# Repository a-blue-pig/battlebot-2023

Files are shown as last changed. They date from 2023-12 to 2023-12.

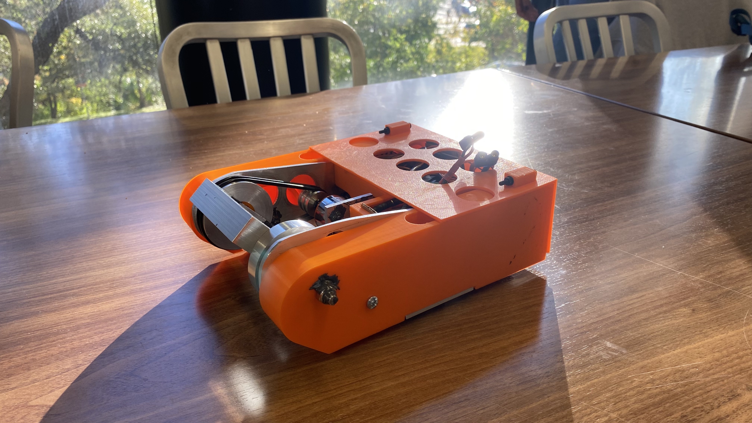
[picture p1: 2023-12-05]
pictures/IMG_2329.jpeg

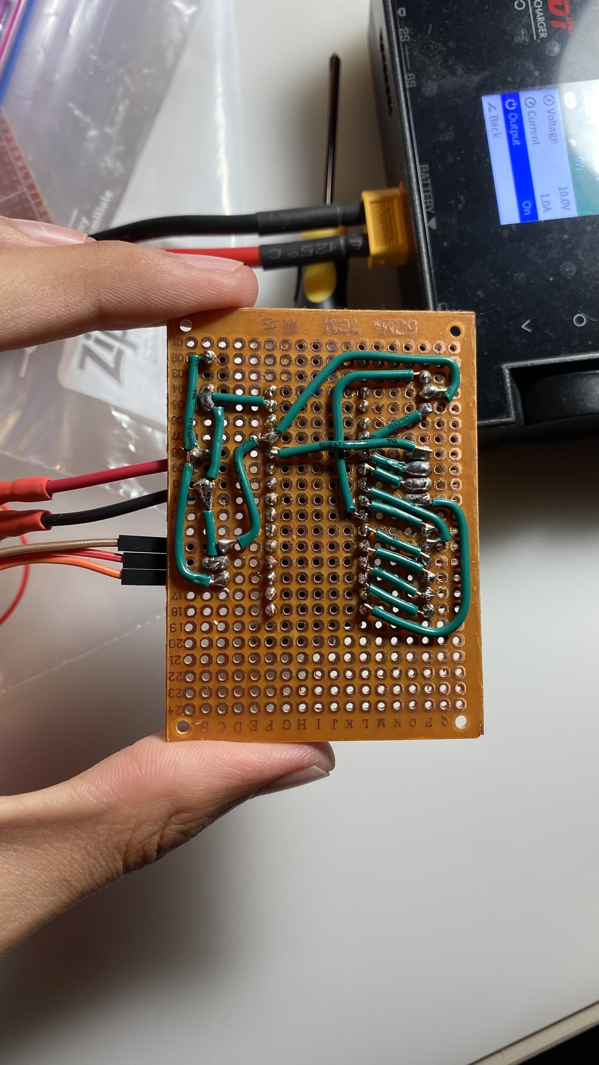
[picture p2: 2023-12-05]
pictures/IMG_2281.jpeg

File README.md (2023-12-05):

# battlebot-2023
BattleBot Project for ME366J

Course Completed in FALL 2023.

## Project Materials
### Microcontroller
Project uses an Arduino Nano Every as the microcontroller.
Requires the following packages/board packages:
1. Servo.
2. Arduino megaAVR Boards.

### Drivetrain
Differential Drive with 2 Motors.
Motor Controller is an L298N.

### Weapon
Weapon is a vertical spinner, made of Aluminum.
It is powered by a 30A ESC with a 2212 2200Kv Motor on a pulley with a 
2.3:1 gear ratio to add torque.

### Controller
Uses a generic RC car controller with 4 Channels.

### Power
Powered using a 3S 1300mAh Lipo.

## Usage/Controls
* The speed channel controls forward and backward movement.
* The steering channel allows for pivoting in place.
    * When combined with speed, it drives like a normal car.
* Channel 3 activates/deactivates the weapon.
* Channel 4 is a software E-Stop.

## Notes about the project
In this project we utilized various engineering practices to create a
battle bot from scratch. Our budget was $300 and we were given ~ 4 weeks
to procure and build our battlebot.

Based on the component we bought we realized our selection of RC
controller had a lot of noise and would not always send signals when
channel 3 and 4 were pressed. As a result I had to get creative in how to
determine if the signal was a true on or true off for the weapon activatiaon.

Overall this project was a strong learning experience and allowed me to
try out kiCAD when drawing our schematics and designing a custom PCB.
The PCB was ultimately made by hand using a protoboard and wires, but was
a unique experience.

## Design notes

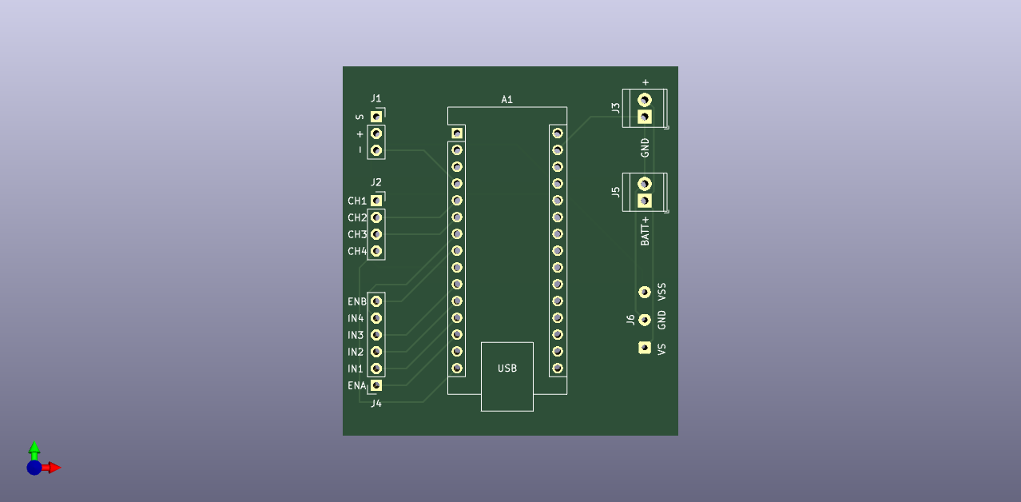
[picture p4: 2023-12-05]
reference-diagrams/PCB/battlebot_pcb_render.tiff

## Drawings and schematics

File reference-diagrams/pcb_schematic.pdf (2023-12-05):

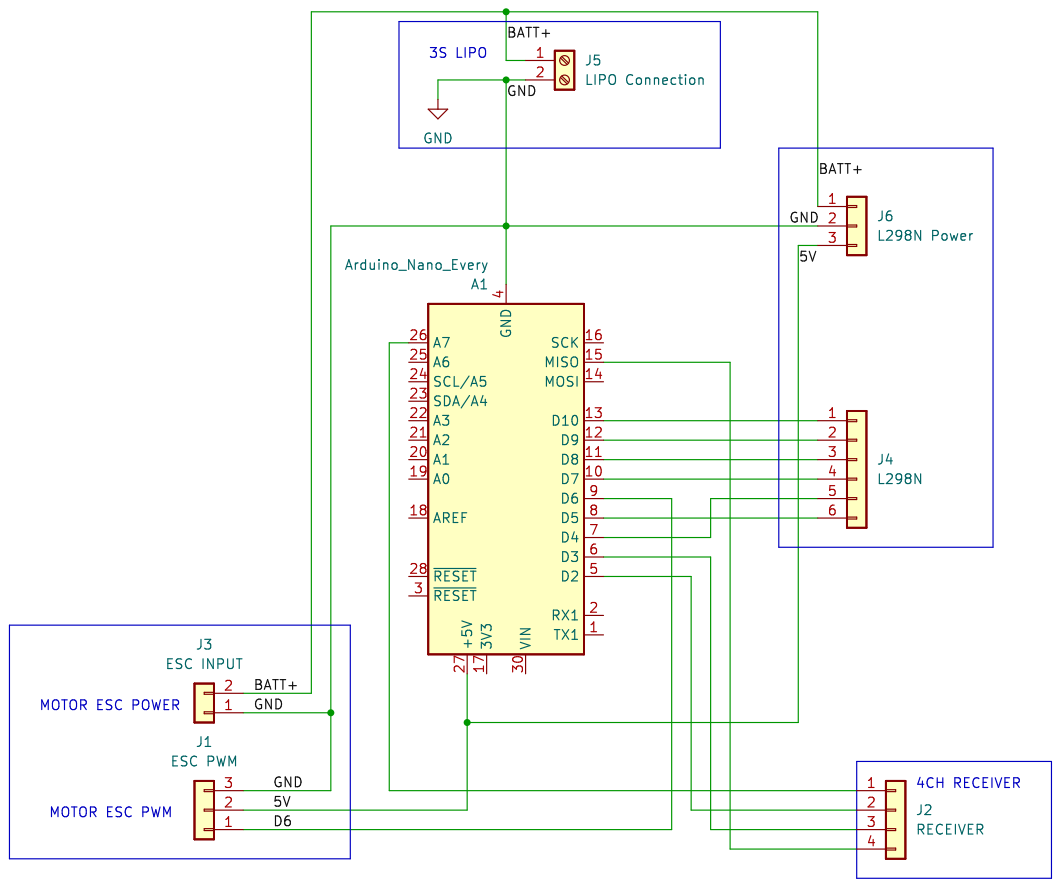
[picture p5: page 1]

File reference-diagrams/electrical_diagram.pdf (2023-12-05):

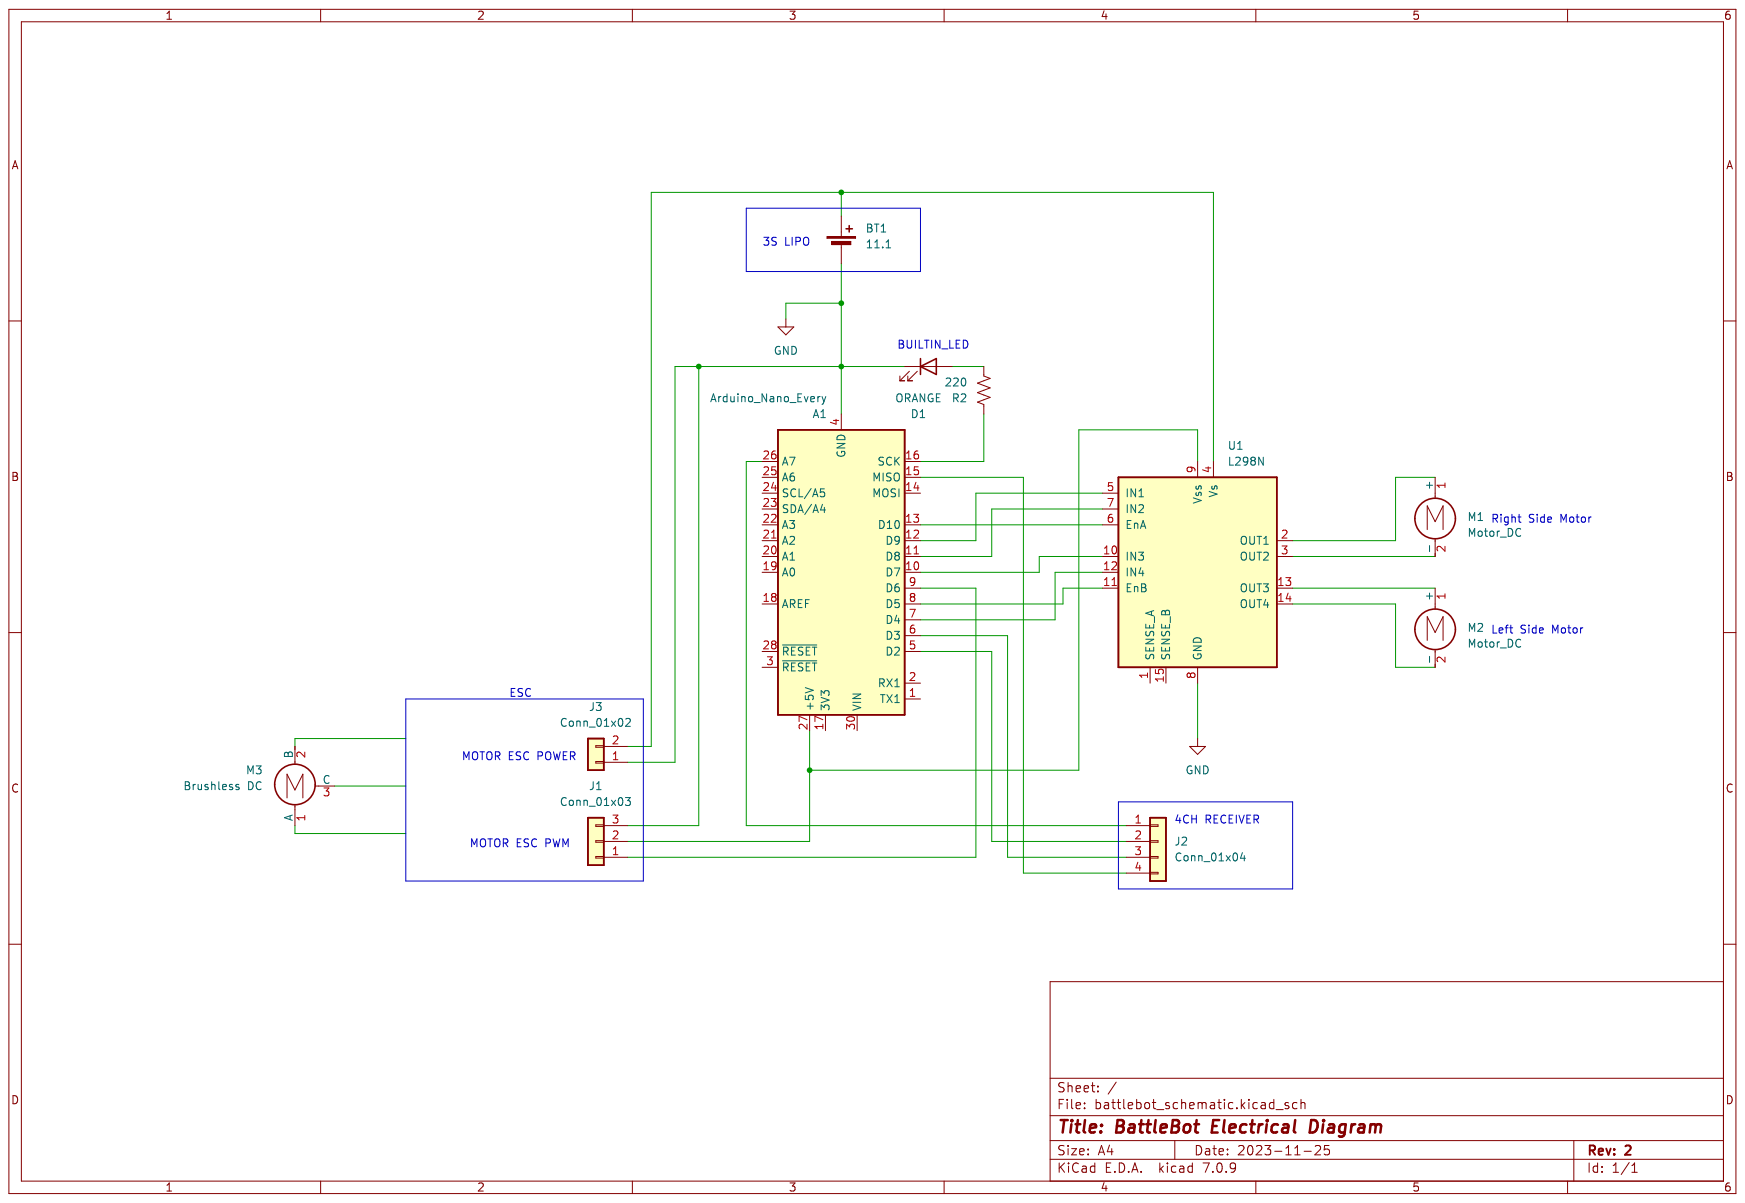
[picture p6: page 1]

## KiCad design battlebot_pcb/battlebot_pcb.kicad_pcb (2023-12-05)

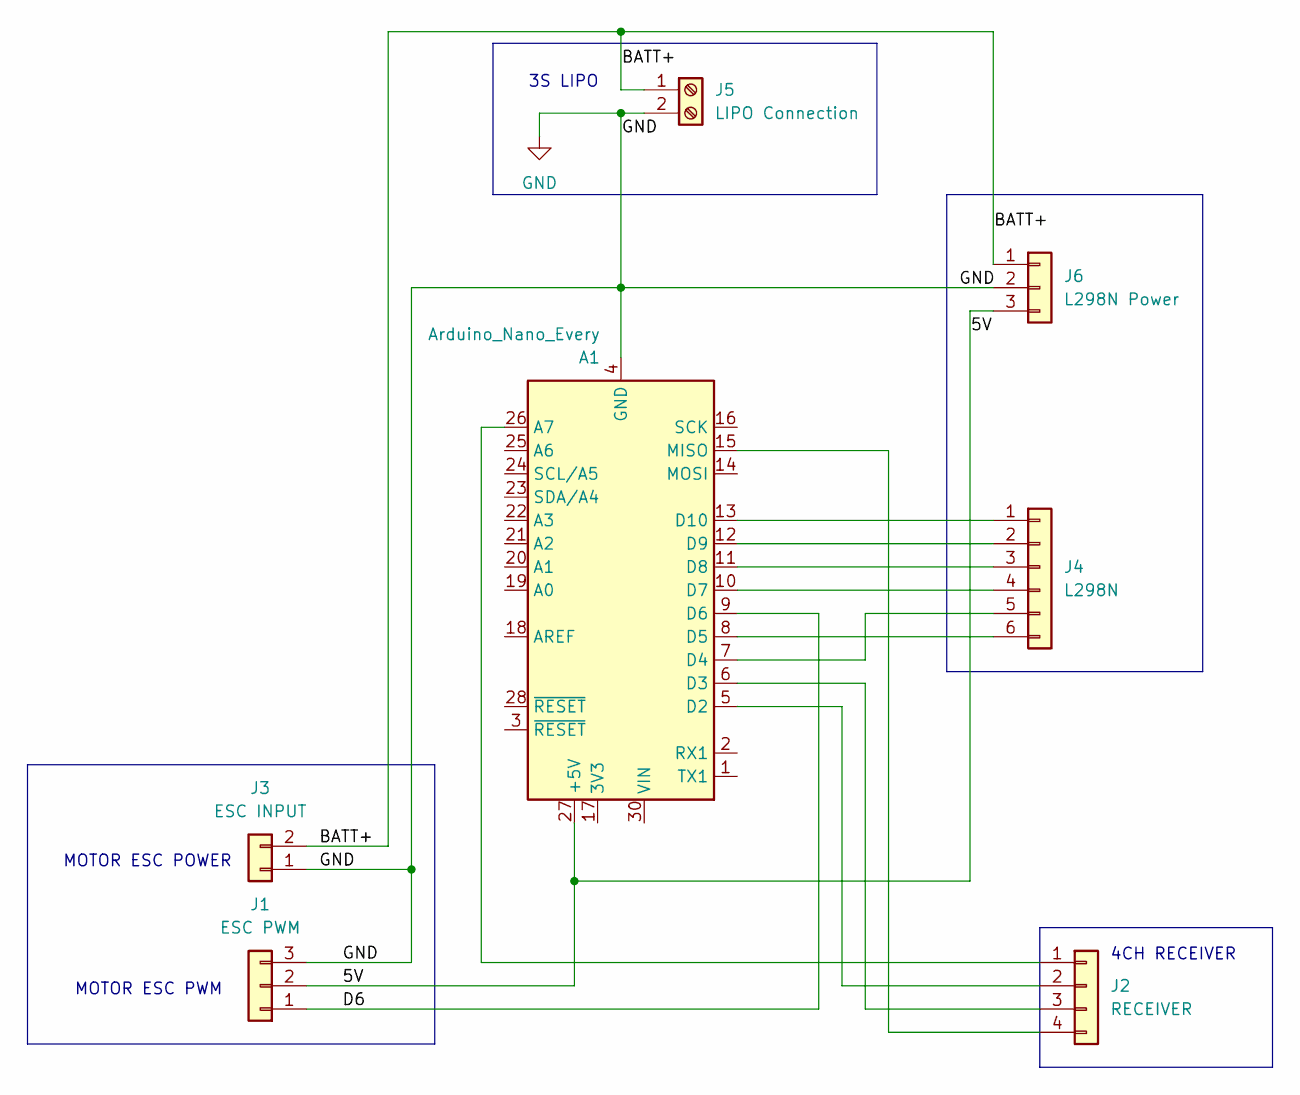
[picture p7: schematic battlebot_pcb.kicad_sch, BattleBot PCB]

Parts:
A1: Arduino_Nano_Every; Arduino_Nano
J1: ESC PWM; PinSocket_1x03_P2.54mm_Vertical
J2: RECEIVER; PinSocket_1x04_P2.54mm_Vertical
J3: ESC INPUT; TerminalBlock_TE_282834-2_1x02_P2.54mm_Horizontal
J4: L298N; PinSocket_1x06_P2.54mm_Vertical
J5: LIPO Connection; TerminalBlock_TE_282834-2_1x02_P2.54mm_Horizontal
J6: L298N Power; SolderWire-0.75sqmm_1x03_P4.8mm_D1.25mm_OD2.3mm

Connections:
/5V: A1.27 (+5V), J1.2, J6.3
/BATT+: J3.2, J5.1, J6.1
/D6: A1.9 (D6), J1.1
GND: A1.4 (GND), A1.29 (GND), J1.3, J3.1, J5.2, J6.2
unnamed: A1.26 (A7), J2.1
unnamed: A1.5 (D2), J2.2
unnamed: A1.6 (D3), J2.3
unnamed: A1.7 (D4), J4.5
unnamed: A1.8 (D5), J4.6
unnamed: A1.10 (D7), J4.4
unnamed: A1.11 (D8), J4.3
unnamed: A1.12 (D9), J4.2
unnamed: A1.13 (D10), J4.1
unnamed: A1.15 (MISO), J2.4

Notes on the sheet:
MOTOR ESC POWER
4CH RECEIVER
MOTOR ESC PWM
3S LIPO

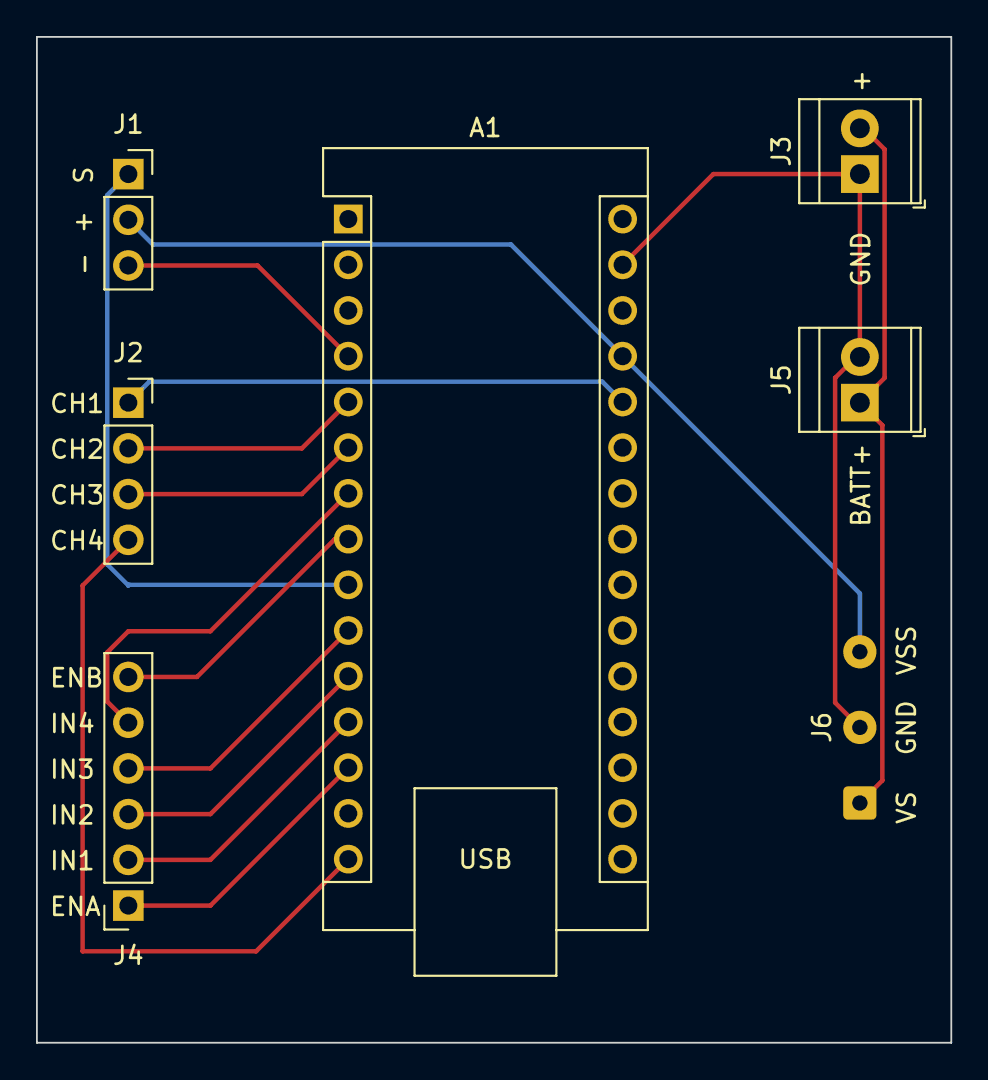
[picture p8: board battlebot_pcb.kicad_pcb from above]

Board: 2 copper layers, 50.8 x 55.9 mm, 7 parts (0 on the bottom side), 14 nets.

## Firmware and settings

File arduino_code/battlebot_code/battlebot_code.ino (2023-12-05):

/*
Steven Ortega
ME366J
Fall 2023

Code for a battlebot. Recieves commands from a RC reciever
and controls the drive train and weapon.

Last Updated 12.3.2023
*/

#include <Servo.h>

// Define Pins
#define CH1 21     // reciever inputs
#define CH2 2
#define CH3 3
#define CH4 12

#define ENA 10     // right side
#define IN1 9
#define IN2 8

#define ENB 5    // left side
#define IN3 7
#define IN4 4

#define WM 6      // Weapon motor
Servo weaponESC;

// pin Interrupt - Read channel values
volatile long startTime1 = 0;       // ch1
volatile long currentTime1 = 0;
volatile long pulses1 = 0;
int ch1Val = 0;

volatile long startTime2 = 0;       // ch2
volatile long currentTime2 = 0;
volatile long pulses2 = 0;
int ch2Val = 0;

volatile long startTime3 = 0;       // ch3
volatile long currentTime3 = 0;
volatile long pulses3 = 0;
int ch3Val = 2000;

volatile long startTime4 = 0;       // ch4
volatile long currentTime4 = 0;
volatile long pulses4 = 0;
int ch4Val = 0;


// pwm value mapping
const int ch1Max = 1960;    // ch1
const int ch1Min = 952;
const int ch1Resting = 1468;

const int ch2Max = 1976;    // ch2
const int ch2Min = 1012;
const int ch2Resting = 1528;

const int deadzone = 50;
int adjAmount = 0;
const int pwmLowerLimit = 10;

// Set_Direction()
char prevDir = 's';     // Begin in stopped state

// Weapon
const int ch3ActiveVal = 1200;
int confirmCount = 0;
bool prevStatusOn = 0;
const int weaponLow = 1300;     // [us] micro seconds
bool weaponOn = 0;
bool leaveWeaponOn = 0;
int confirmOffCount = 0;
long weaponPrevMillis = 0;               // [ms] milliseconds
int val = 0;


// Params to set
bool weaponPulse = 0;                    // Set true if you want the weapon to pulse
const long weaponPulseInterval = 1400;   // [ms] milliseconds
const int weaponHigh = 1500;             // [us] micro seconds
const int minWeaponCount = 10;



void setup() {
  Serial.begin(9600);

  // Setup pins to read channels
  pinMode(CH1, INPUT);
  pinMode(CH2, INPUT);
  pinMode(CH3, INPUT);
  pinMode(CH4, INPUT);
  attachInterrupt(digitalPinToInterrupt(CH1), pulse_timer1, CHANGE);
  attachInterrupt(digitalPinToInterrupt(CH2), pulse_timer2, CHANGE);
  attachInterrupt(digitalPinToInterrupt(CH3), pulse_timer3, CHANGE);
  attachInterrupt(digitalPinToInterrupt(CH4), pulse_timer4, CHANGE);

  // Setup pins to control motors
  pinMode(IN1, OUTPUT);
  pinMode(IN2, OUTPUT);
  pinMode(IN3, OUTPUT);
  pinMode(IN4, OUTPUT);
  pinMode(LED_BUILTIN, OUTPUT);

  digitalWrite(LED_BUILTIN, LOW);
  weaponESC.attach(WM);
  weaponESC.writeMicroseconds(weaponLow);
  delay(5000);
  digitalWrite(LED_BUILTIN, HIGH);
}

void loop() {
  // only save pulses less than 2000 microseconds
  if (pulses1 < 2000){
    ch1Val = pulses1;
  }
  if (pulses2 < 2000){
    ch2Val = pulses2;
  }
  if (pulses3 < 2000){
    ch3Val = pulses3;
  }
  if (pulses4 < 2000){
    ch4Val = pulses4;
  }

  // E-Stop
  if (ch4Val == 1000){
    Serial.println(". E-Stop Activated");
    eStop();
    while (1);
  }

  // reciever_test();
  // Serial.println(ch3Val);

  // Determine if ch3 truly off
  if (ch3Val < ch3ActiveVal) {
    if (prevStatusOn && (confirmCount < minWeaponCount)){
      confirmCount++;
      confirmOffCount = 0;
    }
    prevStatusOn = 1;
  } else {
    confirmOffCount++;
    if (confirmOffCount > 10) {
      confirmCount = 0;
      prevStatusOn = 0;
      confirmOffCount = 0;
    }
  }

  // Weapon Operation
  if (confirmCount == minWeaponCount) {
    weaponESC.writeMicroseconds(weaponLow);  
    // if (weaponOn){
    Serial.println("Weapon Off");  
    // }
    weaponOn = 0;
  } else {
    Serial.println("Weapon On");  
    if (weaponPulse){
      // pulse the weapon
      unsigned long weaponCurrentMillis = millis();
      if (weaponCurrentMillis - weaponPrevMillis >= weaponPulseInterval) {
        weaponPrevMillis = weaponCurrentMillis;
        if (!weaponOn){
          for (val = weaponLow; val <= 1400; val += 25) {
            weaponESC.writeMicroseconds(val);
            delay(500);
          }
          for (val = 1400; val <= weaponHigh; val += 25) {
            weaponESC.writeMicroseconds(val);
            delay(100);
          }
          weaponESC.writeMicroseconds(weaponHigh);
          weaponOn = 1;
          // Serial.println("Weapon Spinning");

        // Make the weapon stay on for twice as long as the interval
        } else if (leaveWeaponOn) {
          weaponESC.writeMicroseconds(weaponLow);
          weaponOn = 0;
          leaveWeaponOn = 0;
        } else {
          leaveWeaponOn = 1;
        }
      }
    } else {
      if (!weaponOn){
        for (val = weaponLow; val <= 1400; val += 25) {
          weaponESC.writeMicroseconds(val);
          delay(500);
        }
        for (val = 1400; val <= weaponHigh; val += 25) {
          weaponESC.writeMicroseconds(val);
          delay(100);
        }
        weaponOn = 1;
      } else {
        weaponESC.writeMicroseconds(weaponHigh);
        weaponOn = 1;
      }
    }
  }

  // Move Forward
  if (ch2Val > (ch2Resting+deadzone)) {
    set_direction('f');
    // Serial.println("forward");

    // Turn Left
    if (ch1Val > (ch1Resting+deadzone)) {
      // slow down turn inner wheel
      adjAmount = (ch1Val - ch1Resting);
      if (adjAmount > (ch2Val-ch2Resting)){
        adjAmount = ch2Val-ch2Resting;
      }
      float pwmOut = map(ch2Val, ch2Resting+deadzone, ch2Max, 0, 255);
      float pwmAdj = abs(map(ch2Val-adjAmount, ch2Resting, ch2Max, pwmLowerLimit, 255));

      // turn left
      analogWrite(ENA, pwmAdj);
      analogWrite(ENB, pwmOut);

      //Serial.println("forward left");
    // Turn. Right
    } else if (ch1Val < (ch1Resting-deadzone)) {
      // slow down turn inner wheel
      adjAmount = (ch1Resting - ch1Val);
      if (adjAmount > (ch2Val-ch2Resting)){
        adjAmount = ch2Val-ch2Resting;
      }
      float pwmOut = map(ch2Val, ch2Resting-deadzone, ch2Max, 0, 255);
      float pwmAdj = abs(map(ch2Val-adjAmount, ch2Resting, ch2Max, pwmLowerLimit, 255));

      // turn right
      analogWrite(ENA, pwmOut);
      analogWrite(ENB, pwmAdj);

      // Serial.println("forward right");

    // Only Forward
    } else {
      float pwmOut = map(ch2Val, ch2Resting+deadzone, ch2Max, 0, 255);
      analogWrite(ENA, pwmOut);
      analogWrite(ENB, pwmOut);
    }

  // Move Backward
  } else if (ch2Val < (ch2Resting-deadzone)) {
    set_direction('b');
    // Serial.println("backward");

    // turn backward left
    if (ch1Val > (ch1Resting+deadzone)) {
      adjAmount = (ch1Val - ch1Resting);
      if (adjAmount > (ch2Resting-ch2Val)){
        adjAmount = ch2Resting-ch2Val;
      }
      float pwmOut = map(ch2Val, ch2Min, ch2Resting+deadzone, 255, 0);
      float pwmAdj = abs(map(ch2Val+adjAmount, ch2Min, ch2Resting, 255, pwmLowerLimit));

      // turn backwards left
      analogWrite(ENA, pwmAdj);
      analogWrite(ENB, pwmOut);

      // Serial.println("backward left");

    // turn backwards right
    } else if (ch1Val < (ch1Resting - deadzone)) {
      adjAmount = (ch1Resting - ch1Val);
      if (adjAmount > (ch2Resting-ch2Val)){
        adjAmount = ch2Resting-ch2Val;
      }
      float pwmOut = map(ch2Val, ch2Min, ch2Resting-deadzone, 255, 0);
      float pwmAdj = abs(map(ch2Val+adjAmount, ch2Min, ch2Resting, 255, pwmLowerLimit));

      // turn backwards right
      analogWrite(ENA, pwmOut);
      analogWrite(ENB, pwmAdj);

      // Serial.println("backward right");

    // Only Backward
    } else {
      float pwmOut = map(ch2Val, ch2Min, ch2Resting-deadzone, 255, 0);
      analogWrite(ENA, pwmOut);
      analogWrite(ENB, pwmOut);
    }

  // Pivoting Manuevers
  } else {

    // Pivot CCW
    if (ch1Val > (ch1Resting+deadzone)) {
      set_direction('l');
      float pwmOut = map(ch1Val, ch1Resting+deadzone, ch1Max, pwmLowerLimit, 255);
      analogWrite(ENA, pwmOut);
      analogWrite(ENB, pwmOut);
      // Serial.println("pivot left");

    // Pivot CW
    } else if (ch1Val < (ch1Resting-deadzone)) {
      set_direction('r');
      float pwmOut = map(ch1Val, ch1Min, ch1Resting-deadzone, 255, pwmLowerLimit);
      analogWrite(ENA, pwmOut);
      analogWrite(ENB, pwmOut);
      // Serial.println("pivot right");

    // Do Nothing if within the deadzone on both ch1 and ch2
    } else {
      set_direction('s');
      analogWrite(ENA, 0);
      analogWrite(ENB, 0);
      // Serial.println("nothing");
    }
  }
}

// read signal pulse on ch1
void pulse_timer1 (){
  currentTime1 = micros();
  if (currentTime1 > startTime1){
    pulses1 = currentTime1 - startTime1;
    startTime1 = currentTime1;
  }
}

// read signal pulse on ch2
void pulse_timer2 (){
  currentTime2 = micros();
  if (currentTime2 > startTime2){
    pulses2 = currentTime2 - startTime2;
    startTime2 = currentTime2;
  }
}

// read signal pulse on ch3
void pulse_timer3 () {
  currentTime3 = micros();
  if (currentTime3 > startTime3){
    pulses3 = currentTime3 - startTime3;
    startTime3 = currentTime3;
  }
}

void pulse_timer4 () {
  currentTime4 = micros();
  if (currentTime4 > startTime4){
    pulses4 = currentTime4 - startTime4;
    startTime4 = currentTime4;
  }
}
// set direction of motors
void set_direction(char dir) {
  if (dir == prevDir){
    return;
  }
  switch (dir){
    case 'l':
      digitalWrite(IN1, LOW);
      digitalWrite(IN2, HIGH);
      digitalWrite(IN3, HIGH);
      digitalWrite(IN4, LOW);
      break;
    case 'r':
      digitalWrite(IN1, HIGH);
      digitalWrite(IN2, LOW);
      digitalWrite(IN3, LOW);
      digitalWrite(IN4, HIGH);
      break;
    case 'f':
      digitalWrite(IN1, HIGH);
      digitalWrite(IN2, LOW);
      digitalWrite(IN3, HIGH);
      digitalWrite(IN4, LOW);
      break;
    case 'b':
      digitalWrite(IN1, LOW);
      digitalWrite(IN2, HIGH);
      digitalWrite(IN3, LOW);
      digitalWrite(IN4, HIGH);
      break;
    case 's':
      digitalWrite(IN1, LOW);
      digitalWrite(IN2, LOW);
      digitalWrite(IN3, LOW);
      digitalWrite(IN4, LOW);
      break;
    default:
      digitalWrite(IN1, LOW);
      digitalWrite(IN2, LOW);
      digitalWrite(IN3, LOW);
      digitalWrite(IN4, LOW);
      break;
  }
  prevDir = dir;
}

void eStop() {
  weaponESC.writeMicroseconds(weaponLow);
  analogWrite(ENA, 0);
  analogWrite(ENB, 0);
  set_direction('s');
  digitalWrite(LED_BUILTIN, LOW);
}

void reciever_test(){
  Serial.print("Ch1: ");
  Serial.print(ch1Val);
  Serial.print(",  Ch2: ");
  Serial.print(ch2Val);
  Serial.print(",  Ch3: ");
  Serial.print(ch3Val);
  Serial.print(",  Ch4: ");
  Serial.println(ch4Val);
}

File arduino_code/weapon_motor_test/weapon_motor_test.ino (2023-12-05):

#include <Servo.h>


#define WM 6      // Weapon motor
Servo weaponESC;
int pos = 0;

void setup() {
  // put your setup code here, to run once:
  pinMode(LED_BUILTIN, OUTPUT);
  digitalWrite(LED_BUILTIN, LOW);
  weaponESC.attach(WM);
  weaponESC.writeMicroseconds(1300);
  delay(3000);
  digitalWrite(LED_BUILTIN, HIGH);
}

void loop() {
  // digitalWrite(LED_BUILTIN, HIGH);
  // weaponESC.writeMicroseconds(1400);
  // delay(2000);
  // digitalWrite(LED_BUILTIN, LOW);
  // weaponESC.writeMicroseconds(1300);
  // delay(2000);

  for (pos = 1300; pos <= 1400; pos += 25) {
    weaponESC.writeMicroseconds(pos);
    delay(500);
  }
  digitalWrite(LED_BUILTIN, LOW);
  delay(300);
  digitalWrite(LED_BUILTIN, HIGH);
  delay(300);
  digitalWrite(LED_BUILTIN, LOW);

  for (pos = 1400; pos <= 1800; pos += 25) {
    weaponESC.writeMicroseconds(pos);
    delay(100);
  }

  digitalWrite(LED_BUILTIN, HIGH);
  delay(300);
  digitalWrite(LED_BUILTIN, LOW);
  delay(300);
  digitalWrite(LED_BUILTIN, HIGH);
}

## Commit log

2023-12-05 Adding BattleBot Arduino code, PCB/schematic projects
    [batttlebot_pcb.kicad_pcb, batttlebot_pcb.kicad_sch]
2023-12-05 circuit schematic and pcb outline
    [battlebot_schematic.kicad_pcb, battlebot_schematic.kicad_sch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]
2023-12-05 added pdf of schematic and pcb layout
2023-12-05 adding arduino pinout
2023-12-05 updated electrical diagrams
    [battlebot_schematic.kicad_sch, batttlebot_pcb.kicad_sch]
2023-12-05 Added weapon pulsing, fixed weaponlow bug, reorg reference
    [battlebot_code.ino]
2023-12-05 rename battlebot_pcb, update dates and revisions on sheets
    [battlebot_pcb-B_Cu.gbr, battlebot_pcb-B_Mask.gbr, battlebot_pcb-B_Paste.gbr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]
2023-12-05 Updated CH4 pin; increased the weaponLow value; Still working on unexpected weapon pulsing.
2023-12-05 Fixed weapon pulsing, Fixed motor orientation issue.
    [battlebot_code.ino, weapon_motor_test.ino]
2023-12-05 Closes #5; Motor ramps up before going to desired speed
